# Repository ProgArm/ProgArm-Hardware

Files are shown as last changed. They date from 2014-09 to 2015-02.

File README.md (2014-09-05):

ProgArm-Hardware
================

This repository contains only schematic and PCB files. Schematic PDF and Gerber files are attached to every [release](https://github.com/ProgArm/ProgArm-Hardware/releases).

You can find other files used in ProgArm project [in other repositories](https://github.com/ProgArm). 

Contributing
------------
If you have found a bug, please consider creating an [issue](https://github.com/ProgArm/ProgArm-Hardware/issues). If you have a question, please [ask it on our website](http://progarm.org/Ask).

Please set up these [filters](http://git-scm.com/book/en/Customizing-Git-Git-Attributes) before commiting to this repository:
```
git config --global filter.cleansch.clean "sed 's/^Date.*$/Date \"\"/'"
git config --global filter.cleanlib.clean "sed 's/^\(EESchema-LIBRARY Version [^ \\t]*\).*$/\1/'"
git config --global filter.cleanpcb.clean "sed 's/\(host pcbnew \"\)[^\"]*/\1/'"
git config --global filter.cleanpro.clean "sed 's/^\(update=\).*$/\1/'"
```

License
-------
[According to](https://www.gnu.org/licenses/gpl-faq.html#GPLOtherThanSoftware) Free Software Foundation, GPL license can be applied to anything as long as we can clearly define 'source code'. In this repository all Kicad files are considered as source code files (*.sch *.kicad_pcb *.lib *.mod and several others). You must provide these files (or their modifications) if you are distributing any work based on this project. Please refer to [LICENSE](https://github.com/ProgArm/ProgArm-Hardware/blob/master/LICENSE) file for details.

    ProgArm is free hardware & software: you can redistribute it and/or modify
    it under the terms of the GNU General Public License as published by
    the Free Software Foundation, either version 3 of the License, or
    (at your option) any later version.

    This program is distributed in the hope that it will be useful,
    but WITHOUT ANY WARRANTY; without even the implied warranty of
    MERCHANTABILITY or FITNESS FOR A PARTICULAR PURPOSE.  See the
    GNU General Public License for more details.

    You should have received a copy of the GNU General Public License
    along with this program.  If not, see <http://www.gnu.org/licenses/>.

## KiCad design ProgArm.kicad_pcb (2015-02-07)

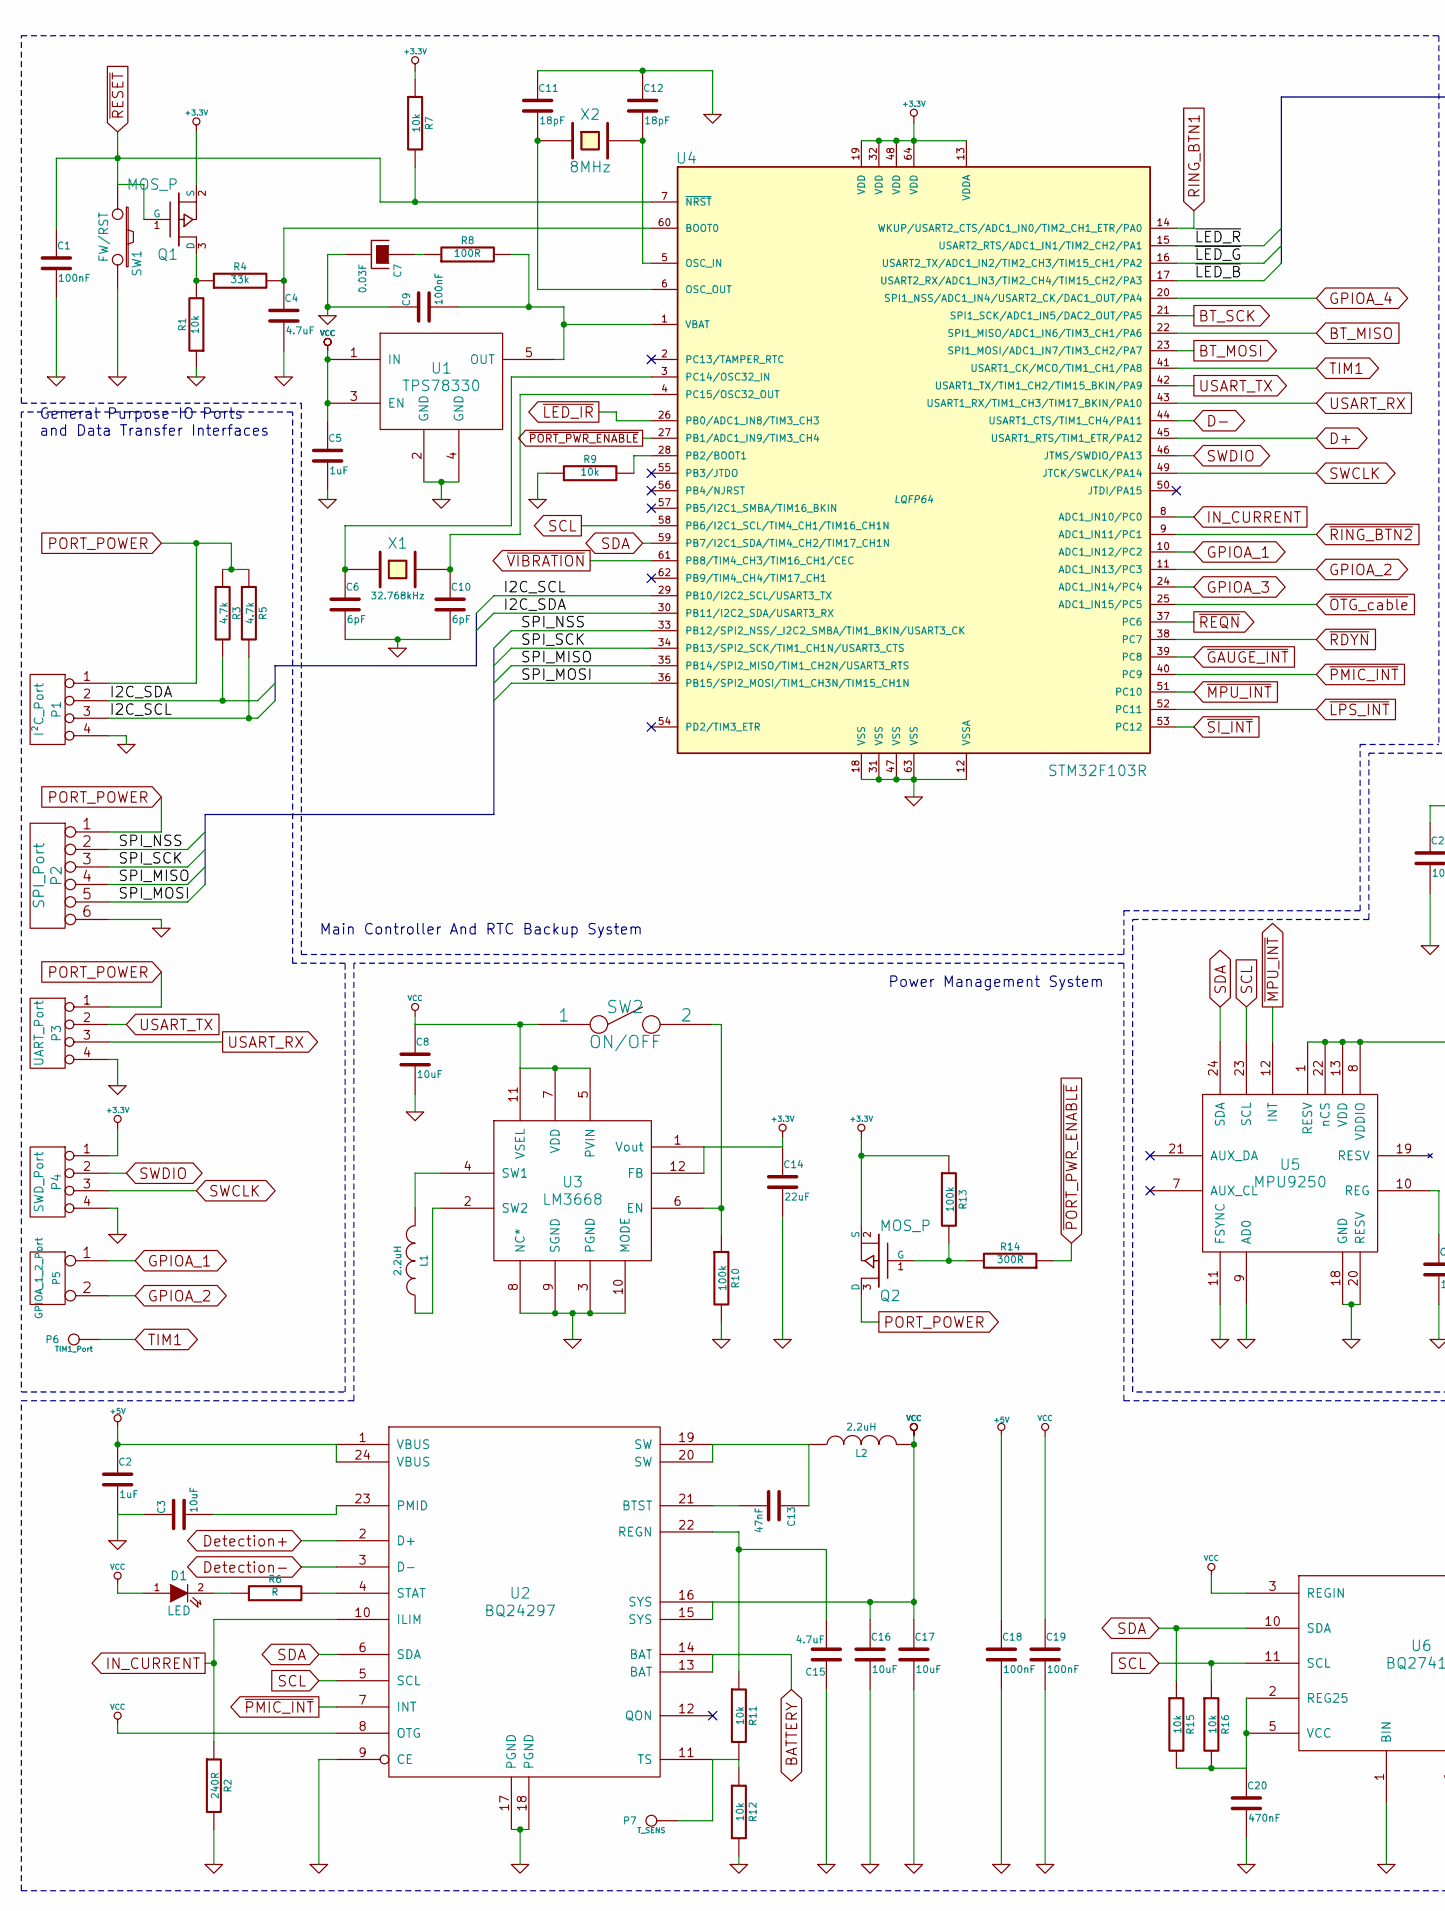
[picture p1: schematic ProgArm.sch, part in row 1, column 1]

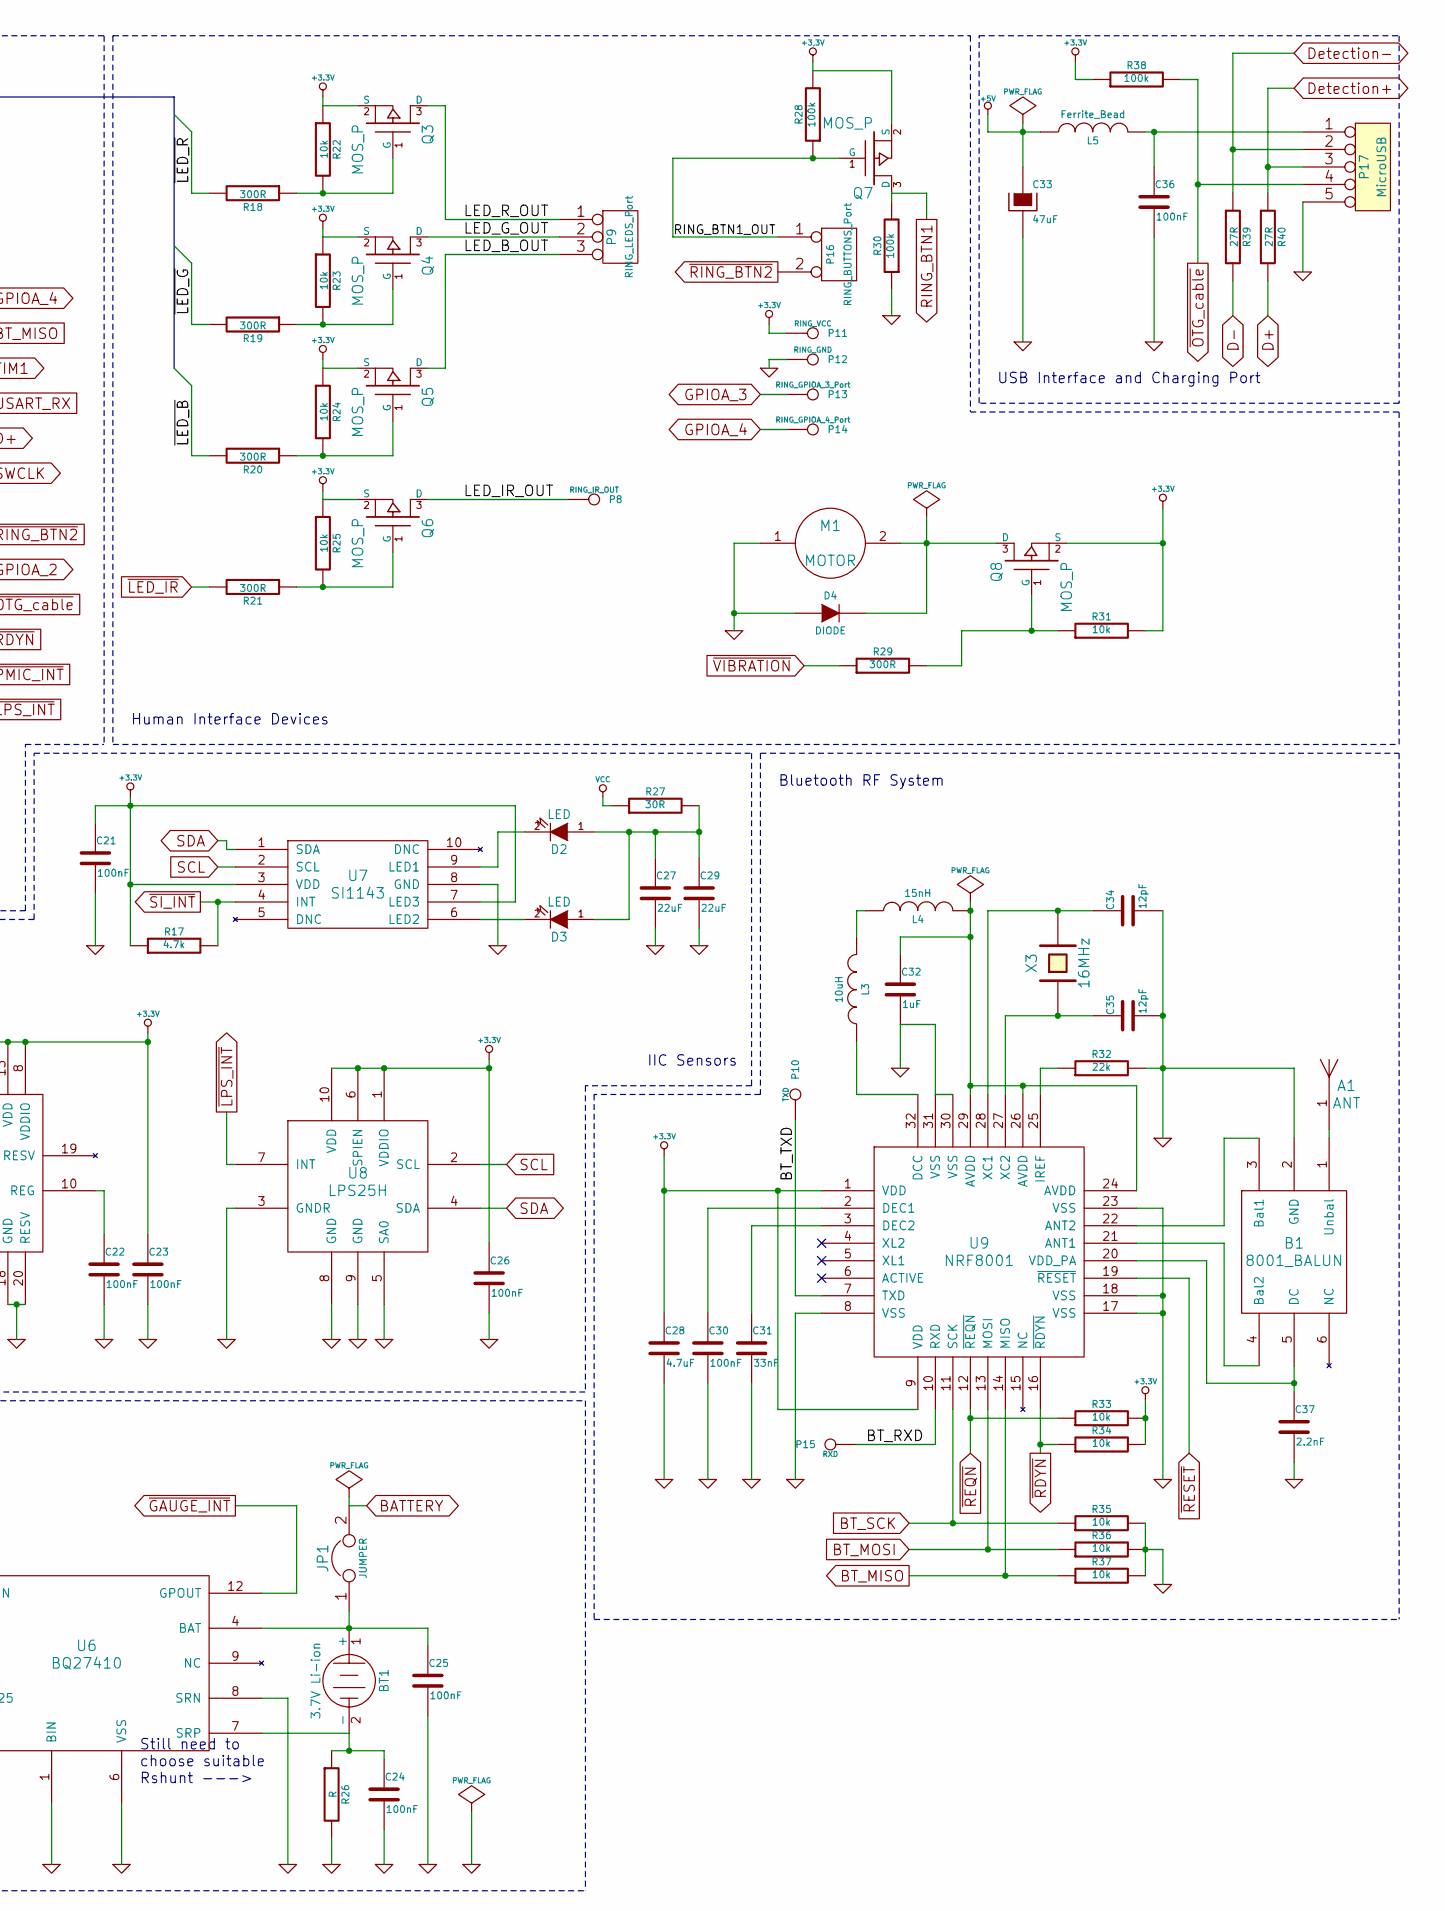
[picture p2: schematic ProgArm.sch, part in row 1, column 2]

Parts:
A1: ANT
B1: 8001_BALUN
BT1: 3.7V Li-ion
C1, C9, C18, C19, C21, C22, C23, C24, C25, C26, C30, C36: 100nF
C2, C5, C32: 1uF
C3, C8, C16, C17: 10uF
C4, C15, C28: 4.7uF
C6, C10: 6pF
C7: 0.03F
C11, C12: 18pF
C13: 47nF
C14, C27, C29: 22uF
C20: 470nF
C31: 33nF
C33: 47uF
C34, C35: 12pF
C37: 2.2nF
D1, D2, D3: LED
D4: DIODE
JP1: JUMPER
L1, L2: 2.2uH
L3: 10uH
L4: 15nH
L5: Ferrite_Bead
M1: MOTOR
P1: I²C_Port
P2: SPI_Port
P3: UART_Port
P4: SWD_Port
P5: GPIOA_1_2_Port
P6: TIM1_Port
P7: T_SENS
P8: RING_IR_OUT
P9: RING_LEDS_Port
P10: TXD
P11: RING_VCC
P12: RING_GND
P13: RING_GPIOA_3_Port
P14: RING_GPIOA_4_Port
P15: RXD
P16: RING_BUTTONS_Port
P17: MicroUSB
Q1, Q2, Q3, Q4, Q5, Q6, Q7, Q8: MOS_P
R1, R7, R9, R11, R12, R15, R16, R22, R23, R24, R25, R31, R33, R34, R35, R36, R37: 10k
R2: 240R
R3, R5, R17: 4.7k
R4: 33k
R6, R26: R
R8: 100R
R10, R13, R28, R30, R38: 100k
R14, R18, R19, R20, R21, R29: 300R
R27: 30R
R32: 22k
R39, R40: 27R
SW1: FW/RST
SW2: ON/OFF
U1: TPS78330
U2: BQ24297
U3: LM3668
U4: STM32F103R; LQFP64
U5: MPU9250
U6: BQ27410
U7: SI1143
U8: LPS25H
U9: NRF8001
X1: 32.768kHz
X2: 8MHz
X3: 16MHz

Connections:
/BT_RXD: P15.1, U9.10 (RXD)
/BT_TXD: P10.1, U9.7 (TXD)
/I2C_SCL: P1.3, R5.2, U4.29 (PB10/I2C2_SCL/USART3_TX)
/I2C_SDA: P1.2, R3.2, U4.30 (PB11/I2C2_SDA/USART3_RX)
/LED_B_OUT: P9.3, Q5.3 (D)
/LED_G_OUT: P9.2 (PM), Q4.3 (D)
/LED_IR_OUT: P8.1, Q6.3 (D)
/LED_R_OUT: P9.1, Q3.3 (D)
/RING_BTN1_OUT: P16.1, Q7.1 (G), R28.1
/SPI_MISO: P2.4, U4.35 (PB14/SPI2_MISO/TIM1_CH2N/USART3_RTS)
/SPI_MOSI: P2.5, U4.36 (PB15/SPI2_MOSI/TIM1_CH3N/TIM15_CH1N)
/SPI_NSS: P2.2, U4.33 (PB12/SPI2_NSS/_I2C2_SMBA/TIM1_BKIN/USAR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)
/SPI_SCK: P2.3, U4.34 (PB13/SPI2_SCK/TIM1_CH1N/USART3_CTS)
/~LED_B: R20.2, U4.17 (USART2_RX/ADC1_IN3/TIM2_CH4/TIM15_CH2/P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)
/~LED_G: R19.2, U4.16 (USART2_TX/ADC1_IN2/TIM2_CH3/TIM15_CH1/P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)
/~LED_R: R18.2, U4.15 (USART2_RTS/ADC1_IN1/TIM2_CH2/PA1)
BATTERY: JP1.2, U2.13 (BAT), U2.14 (BAT)
BT_MISO: R37.1, U4.22 (SPI1_MISO/ADC1_IN6/TIM3_CH1/PA6), U9.14 (MISO)
BT_MOSI: R36.1, U4.23 (SPI1_MOSI/ADC1_IN7/TIM3_CH2/PA7), U9.13 (MOSI)
BT_SCK: R35.1, U4.21 (SPI1_SCK/ADC1_IN5/DAC2_OUT/PA5), U9.11 (SCK)
D+: R40.2, U4.45 (USART1_RTS/TIM1_ETR/PA12)
D-: R39.2, U4.44 (USART1_CTS/TIM1_CH4/PA11)
Detection+: P17.3, R40.1, U2.2 (D+)
Detection-: P17.2, R39.1, U2.3 (D-)
GND: B1.2 (GND), C1.2, C2.2, C3.1, C4.2, C5.2, C6.2, C7.2, C8.2, C9.1, C10.2, C11.1, C12.1, C14.2, C15.1, C16.2, C17.2, C18.2, C19.2, C20.2, C21.2, C22.2, C23.2, C24.2, C25.2, C26.2, C27.2, C28.2, C29.2, C30.2, C31.2, C32.2, C33.2, C34.2, C35.2, C36.2, C37.2, D4.1 (A), M1.0, M1.1, P1.4, P2.6, P3.4, P4.4, P12.1, P17.0, P17.5, R1.1, R2.2, R9.1, R10.2, R12.2, R26.2, R30.1, R32.2, R35.2, R36.2, R37.2, SW1.2, SW2.0, U1.2 (GND), U1.4 (GND), U2.0, U2.9 (CE), U2.17 (PGND), U2.18 (PGND), U3.0, U3.3 (PGND), U3.8 (NC*), U3.9 (SGND), U3.10 (MODE), U4.12 (VSSA), U4.18 (VSS), U4.31 (VSS), U4.47 (VSS), U4.63 (VSS), U5.9 (AD0), U5.11 (FSYNC), U5.18 (GND), U5.20 (RESV), U6.0, U6.1 (BIN), U6.6 (VSS), U6.8 (SRN), U7.8 (GND), U8.3 (GNDR), U8.5 (SA0), U8.8 (GND), U8.9 (GND), U9.0, U9.8 (VSS), U9.17 (VSS), U9.18 (VSS), U9.23 (VSS), U9.30 (VSS), U9.31 (VSS), X3.0
GPIOA_1: P5.1, U4.10 (ADC1_IN12/PC2)
GPIOA_2: P5.2 (PM), U4.11 (ADC1_IN13/PC3)
GPIOA_3: P13.1, U4.24 (ADC1_IN14/PC4)
GPIOA_4: P14.1, U4.20 (SPI1_NSS/ADC1_IN4/USART2_CK/DAC1_OUT/PA4)
IN_CURRENT: R2.1, U2.10 (ILIM), U4.8 (ADC1_IN10/PC0)
unnamed: L3.1, U9.32 (DCC)
unnamed: B1.4 (Bal2), U9.21 (ANT1)
unnamed: B1.5 (DC), C37.1, U9.20 (VDD_PA)
unnamed: B1.3 (Bal1), U9.22 (ANT2)
unnamed: C22.1, U5.10 (REG)
unnamed: C15.2, R11.1, U2.22 (REGN)
unnamed: P7.1, R11.2, R12.1, U2.11 (TS)
unnamed: L3.2, L4.1
unnamed: R32.1, U9.25 (IREF)
unnamed: C31.1, U9.3 (DEC2)
unnamed: C30.1, U9.2 (DEC1)
unnamed: A1.1, B1.1 (Unbal)
unnamed: Q1.3 (D), R1.2, R4.1
unnamed: BT1.2 (-), C24.1, R26.1, U6.7 (SRP)
unnamed: Q2.1 (G), R13.2, R14.2
unnamed: R10.1, SW2.2, U3.6 (EN)
unnamed: L1.1, U3.2 (SW2)
unnamed: L1.2, U3.4 (SW1)
unnamed: R6.2, U2.4 (STAT)
unnamed: D1.2 (K), R6.1
unnamed: C3.2, U2.23 (PMID)
unnamed: C13.1, L2.1, U2.19 (SW), U2.20 (SW)
unnamed: C13.2, U2.21 (BTST)
unnamed: R9.2, U4.28 (PB2/BOOT1)
unnamed: C10.1, U4.4 (PC15/OSC32_OUT), X1.2
unnamed: C9.2, R8.2, U1.5 (OUT), U4.1 (VBAT)
unnamed: C7.1, R8.1
unnamed: C6.1, U4.3 (PC14/OSC32_IN), X1.1
unnamed: Q6.1 (G), R21.1, R25.2
unnamed: C27.1, C29.1, D2.1 (A), D3.1 (A), R27.2
unnamed: D3.2 (K), U7.6 (LED2)
unnamed: D2.2 (K), U7.9 (LED1)
unnamed: C4.1, R4.2, U4.60 (BOOT0)
unnamed: C20.1, R15.2, R16.2, U6.2 (REG25), U6.5 (VCC)
unnamed: D4.2 (K), M1.2, Q8.3 (D)
unnamed: Q3.1 (G), R18.1, R22.2
unnamed: C11.2, U4.6 (OSC_OUT), X2.1
unnamed: C12.2, U4.5 (OSC_IN), X2.2
unnamed: Q5.1 (G), R20.1, R24.2
unnamed: Q4.1 (G), R19.1, R23.2
unnamed: C36.1, L5.2, P17.1
unnamed: BT1.1 (+), C25.1, JP1.1, U6.4 (BAT)
unnamed: C32.1, L4.2, U9.24 (AVDD), U9.26 (AVDD), U9.29 (AVDD)
unnamed: Q8.1 (G), R29.2, R31.1
unnamed: C34.1, U9.28 (XC1), X3.2
unnamed: C35.1, U9.27 (XC2), X3.1
PORT_POWER: P1.1, P2.1, P3.1, Q2.3 (D), R3.1, R5.1
RING_BTN1: Q7.3 (D), R30.2, U4.14 (WKUP/USART2_CTS/ADC1_IN0/TIM2_CH1_ETR/P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)
SCL: R16.1, U2.5 (SCL), U4.58 (PB6/I2C1_SCL/TIM4_CH1/TIM16_CH1N), U5.23 (SCL), U6.11 (SCL), U7.2 (SCL), U8.2 (SCL)
SDA: R15.1, U2.6 (SDA), U4.59 (PB7/I2C1_SDA/TIM4_CH2/TIM17_CH1N), U5.24 (SDA), U6.10 (SDA), U7.1 (SDA), U8.4 (SDA)
SWCLK: P4.3, U4.49 (JTCK/SWCLK/PA14)
SWDIO: P4.2, U4.46 (JTMS/SWDIO/PA13)
TIM1: P6.1, U4.41 (USART1_CK/MCO/TIM1_CH1/PA8)
USART_RX: P3.3, U4.43 (USART1_RX/TIM1_CH3/TIM17_BKIN/PA10)
USART_TX: P3.2, U4.42 (USART1_TX/TIM1_CH2/TIM15_BKIN/PA9)
~GAUGE_INT: U4.39 (PC8), U6.12 (GPOUT)
~LED_IR: R21.2, U4.26 (PB0/ADC1_IN8/TIM3_CH3)
~LPS_INT: U4.52 (PC11), U8.7 (INT)
~MPU_INT: U4.51 (PC10), U5.12 (INT)
~OTG_cable: P17.4, R38.2, U4.25 (ADC1_IN15/PC5)
~PMIC_INT: U2.7 (INT), U4.40 (PC9)
~PORT_PWR_ENABLE: R14.1, U4.27 (PB1/ADC1_IN9/TIM3_CH4)
~RDYN: R34.1, U4.38 (PC7), U9.16 (~RDYN)
~REQN: R33.1, U4.37 (PC6), U9.12 (~REQN)
~RESET: C1.1, Q1.1 (G), R7.2, SW1.1, U4.7 (~NRST), U9.19 (~RESET)
~RING_BTN2: P16.2 (PM), U4.9 (ADC1_IN11/PC1)
~SI_INT: R17.2, U4.53 (PC12), U7.4 (INT)
~VIBRATION: R29.1, U4.61 (PB8/TIM4_CH3/TIM16_CH1/CEC)

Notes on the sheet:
Still need to choose suitable Rshunt --->
Power Management System
IIC Sensors
Bluetooth RF System
Human Interface Devices
USB Interface and Charging Port
Main Controller And RTC Backup System
General Purpose IO Ports and Data Transfer Interfaces

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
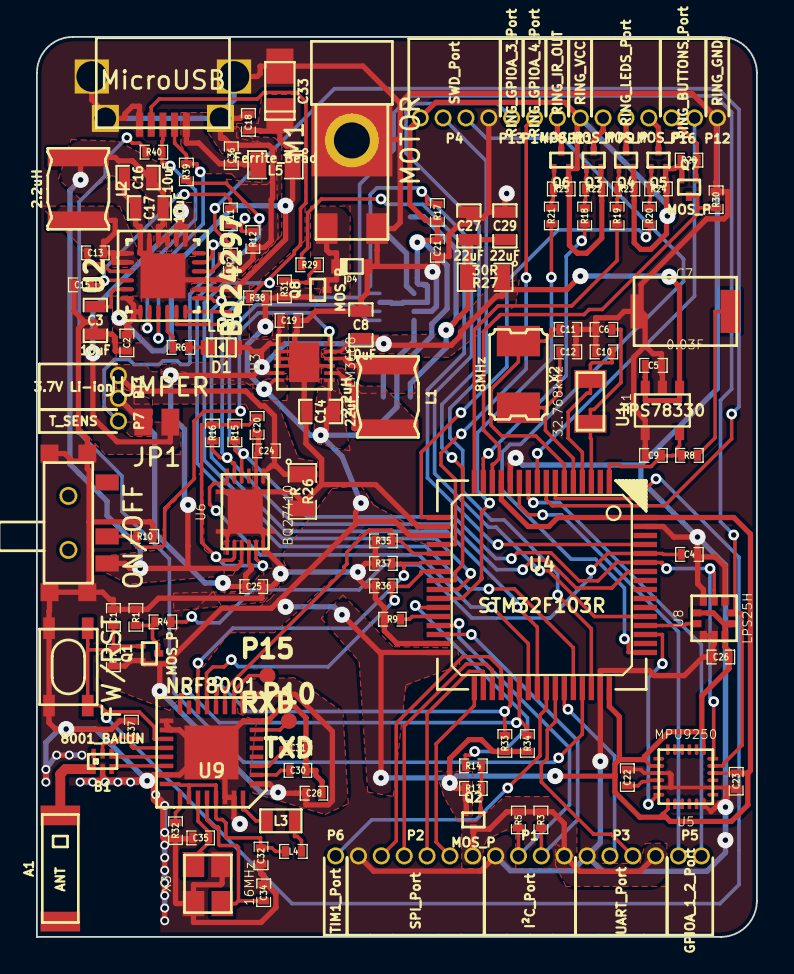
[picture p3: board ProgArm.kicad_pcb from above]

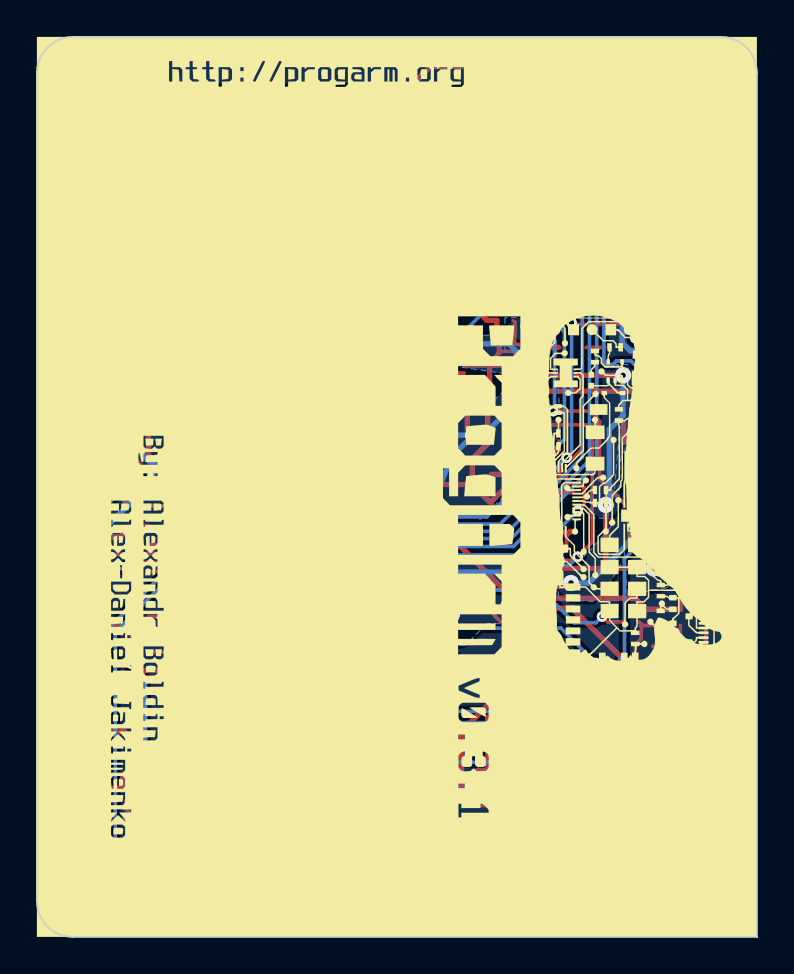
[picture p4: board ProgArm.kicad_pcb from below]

Board: 2 copper layers, 40.0 x 50.0 mm, 131 parts (3 on the bottom side), 101 nets.

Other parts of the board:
VAL: REF; progarm_logo

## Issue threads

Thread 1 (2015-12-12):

No 1.5kOhm pull-up on D+ line

AlexDaniel, 2015-12-12:
One careful person asked this question by email:

> I was wondering, where is 1.5 kOhm pull-up on D+ line?

Indeed! It seems like it is an error on schematic. USB communication was not tested yet, so no wonder that this problem went unnoticed.

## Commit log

2014-06-03 Initial commit. ProgArm 0.1
    [arm.dsn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]
2014-06-03 Fixed external SPI port connection
2014-06-04 True PWM pins for ring port
    [arm.sch]
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2014-06-06 Git filters in action
    [arm.sch]
2014-06-07 Fixed git filter
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2014-06-07 6-pin ring port, RING_BTN2
    [arm.sch]
2014-06-07 Both PIO0 and PIO11 are connected to BT_KEY now. This is required for HM-10 and HC-05 compatibility.
    [arm.sch]
2014-06-07 Implemented an LTC3566-2 power management IC as primary power source / charge controller instead of previous problematic build.
    [arm.sch]
2014-06-08 added piezo buzzer instead of old one
    [arm.sch]
2014-06-09 New super convenient push-button flashing system!
    [arm.sch]
2014-06-10 removed unneeded resistor in flash-enable circuit
    [arm.sch]
2014-06-11 Removed unnecessary RESET global label
    [arm.sch]
2014-06-14 SPI_NSS, extra components for soldering
    [arm.sch]
2014-06-16 i2c pullups set to sys_power, modified firmware switch
    [arm.sch]
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2014-06-18 Added new component to the STM32 library: STM32F103R8; replaced current MCU with it due to more pins required
    [arm.sch]
2014-06-18 Added JTAG, Reassigned pins used by JTAG to PC0-PC15, Connected #PWM_MODE flag, minor fixes and improvements
    [arm.sch]
2014-06-18 Minor visual improvement with BOOT1 pin
    [arm.sch]
2014-06-18 BT_KEY is now near to other BT pins
    [arm.sch]
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2014-06-18 Reassigned SD_CD to pin 24, so that SD card pins would be in order
    [arm.sch]
2014-06-18 new look for inverted global labels (using "~" instead of "#")
    [arm.sch]
2014-06-18 new names for global labels because Alex-Daniel wanted so -_-
    [arm.sch]
2014-06-18 Rearranged MOSFET pullup resistors, ~CHARGE and ALERT moved to PC2 and PC3
    [arm.sch]
2014-06-18 schematic layout changes because Plex-Daniel wanted so...
    [arm.sch]
2014-06-19 Fixed LTC3566 (EXPAD pin number set to 0, made component wider, so that all text would fit)
    [arm.sch]
2014-06-19 Fixed LED bus names
    [arm.sch]
2014-06-19 Not connected pins, minor fixes
    [arm.sch]
2014-06-19 Automatic annotation, generated netlist
    [arm.sch]
2014-06-19 Slowly setting correct footprints
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2014-06-19 More visual improvements, BT bus separated from RING bus, Authors' names
    [arm.sch]
2014-06-19 Renaming all files. arm->ProgArm
    [ProgArm.kicad_pcb, ProgArm.sch]
2014-06-19 Removing outdated specctra and gerber files
    [arm.dsn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]
2014-06-19 Forgot to add PC13 to unused pins. This is now fixed
    [ProgArm.sch]
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2014-06-19 Added separate switchable power line for external ports (~PRT_PWR_ENABLE and PRT_POWER)
    [ProgArm.sch]
2014-06-20 Reorganized the whole schematic! Readability counts.
    [ProgArm.sch]
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2014-06-20 MPU and HMC are using the same 15-10 interrupt now
    [ProgArm.sch]
2014-06-20 Deleted unnecessary library files, replaced our own components with Walter Lain's libraries, moved all library files to 'library' and 'modules' folder, strict convention in component naming (all file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
    [ProgArm.sch]
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2014-06-21 Fixed file permissions, separated buzzer nad stm32f103r components from ProgArm-cache, other minor fixes
    [ProgArm.sch]
2014-06-21 Fixed library order, motor and buzzer are moved into misc.lib, fixed mosfet components, ~OVERLINE for ring led and ring_button2, other minor improvements
    [ProgArm.sch]
2014-06-21 Inverted ALERT, MPU_INT and HMC_INT
    [ProgArm.sch]
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2014-06-21 removed a resistor on MPU_INT
    [ProgArm.sch]
2014-06-21 Setting up footprints. Halfway there (1pin indicates unset footprint)
    [ProgArm.sch]
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2014-06-21 Fixed pin numbering in side switch footprint
2014-06-21 Still setting up footprints! Fixed Ring_Port name (was CONN_6), changed INDUCTOR to Ferrite_Bead
    [ProgArm.sch]
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2014-06-22 Changed directory structure, added 3d files, corrected some footprints in netlist
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2014-06-22 Netlist read! Everything is ready for PCB development. Added kicad_pcb-bak to .gitignore
    [ProgArm.kicad_pcb]
2014-06-22 Revision version specified (0.2), Copyright notice in kicad_pcb file
    [ProgArm.kicad_pcb, ProgArm.sch]
2014-06-22 First try of PCB components positioning
    [ProgArm.kicad_pcb]
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2014-06-22 trying to make PCB
    [ProgArm.dsn, ProgArm.kicad_pcb]
2014-06-22 GND on usb body, no exposed pad for MPU
    [ProgArm.kicad_pcb]
2014-06-22 LTC3566 exposed pad connected to GND
    [ProgArm.kicad_pcb]
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2014-06-23 New board layout attempt
    [ProgArm.dsn, ProgArm.kicad_pcb]
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2014-06-26 Another attempt. Components placed
    [ProgArm.dsn, ProgArm.kicad_pcb]
2014-06-26 Optimized tracks (120 vias, 3,092...)
    [ProgArm.dsn]
2014-06-27 Rearranged PCB Power layout
    [ProgArm.dsn, ProgArm.kicad_pcb]
2014-06-27 Fixed spacing between pins
    [ProgArm.kicad_pcb]
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2014-06-28 LQFP64 pin width changed to 0.3mm, added HMC ground track (otherwise it wont route), updated .dsn file
    [ProgArm.dsn, ProgArm.kicad_pcb]
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2014-06-30 Hacked ProgArm.kicad_pcb file to add another net for LTC2942-1 exposed pad
    [ProgArm.kicad_pcb]
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2014-06-30 Slightly moved tracks and vias to achieve amazing fill zones
    [ProgArm.dsn, ProgArm.kicad_pcb]
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2014-06-30 An attempt to separate exposed pad from pins
    [ProgArm.kicad_pcb]
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2014-06-30 Added cutout area for hmc and mpu (GND was filling inside like an exposed pad)
    [ProgArm.kicad_pcb]
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2014-06-30 All ground pins are now rectangular (keep in mind that .dsn was not changed)
    [ProgArm.kicad_pcb]
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2014-07-01 Slightly modified logo (version number, text moved a little bit so that through-holes do not cover letters)
    [ProgArm.kicad_pcb]
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2014-07-01 Fixed email address
    [ProgArm.kicad_pcb, ProgArm.sch]
2014-07-02 Gerber files are now removed from git repo. Please see Releases (tags) on github to get gerbers and schematic(pdf)
    [ProgArm-B_Cu.gbl, ProgArm-B_Mask.gbs, ProgArm-B_SilkS.gbo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]
2014-07-24 Major bug fix! Added delay system at BOOT0 to prevent STM32 forcing itself into flasing mode after each reset.
    [ProgArm.sch]
2014-08-18 Adjusted some pullup resistors values for better PWM
    [ProgArm.sch]
2014-08-18 Added missing component numbers
    [ProgArm.sch]
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2014-11-09 Removed compass component (we will use something that is integrated with accelgyro)
    [ProgArm.sch]
2014-11-10 Changed SYS_POWER to 3.3v in I2C pullups (because battery chips are always on)
    [ProgArm.sch]
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2014-11-15 Replaced BMP180 with LPS25H, changed HMC_INT to LPS_INT
    [ProgArm.sch]
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2014-11-17 Replaced LTC2942 with bq27410. COrrections still needed,
    [ProgArm.sch]
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2014-11-24 -Replaced LTC3566 with bq24297 -Removed SYS_Power plane, now it's powered from 3.3v -Added dedicated buck-boost converter (lm3668) -Added OTG cable detection and input current sense -Removed 100uF ta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
    [ProgArm.sch]
2014-11-25 Replaced HC05 with custom BT module (nRF51822)
    [ProgArm.sch]
2014-11-25 Fixed Rx Tx pins on BT Chip
    [ProgArm.sch]
2014-11-25 Fixed not connected SD_CD pin
    [ProgArm.sch]
2014-11-25 one of the BT_AVDD power flags should have been set as output
    [ProgArm.sch]
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2014-12-02 Replaced nRF51 series chip with nRF8001; removed SD_CARD
    [ProgArm.sch]
2014-12-03 Added IR LED and Sensor connections for ring port
    [ProgArm.sch]
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2014-12-03 Removed useless elements (buzzer signals, solder ports, NC pins etc.)
    [ProgArm.sch]
2014-12-04 Removed unused third LED in the pulse sensor schematic
    [ProgArm.sch]
2014-12-05 Issue with bluetooth pull-downs
    [ProgArm.sch]
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2014-12-08 Fixed issues from the list, added block-style grouping
    [ProgArm.sch]
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2014-12-08 Pulse meter LEDs are now powered from VCC
    [ProgArm.sch]
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2014-12-08 Components numeration, description fixes
    [ProgArm.sch]
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2014-12-09 Fixed bq27410 footprint
2014-12-09 Fixed qfn-10 footprint
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2014-12-10 Fixed antenna pin number, changed footprints for BT TXD and RXD
    [ProgArm.kicad_pcb, ProgArm.sch]
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2014-12-11 Central pads connected to GND (according to datasheets), no holes on central pads, smaller size for TXD and RXD pads
    [ProgArm.kicad_pcb]
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2014-12-11 Changing trace widths (and rounding it to mm)
    [ProgArm.kicad_pcb]
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2014-12-13 Fixed inductor and switch footprints
2014-12-13 Revert "Fixed inductor and switch footprints"
    (Netnames inside the library files)
    This reverts commit 9a7367a608264bf1beca435706c64097ef592859.
2014-12-13 Fixed inductor and switch footprints (seriously this time)
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2014-12-13 Small fixed, tracks imported
    [ProgArm.kicad_pcb]
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2014-12-18 Small fixes, thick power traces
    [ProgArm.dsn, ProgArm.kicad_pcb]
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2014-12-18 Board Optimized: Via count: 100 Trace Lenght: 2,515,295,8805
    [ProgArm.dsn, ProgArm.kicad_pcb]
2014-12-20 Small fixes for proper power tracks
    [ProgArm.dsn, ProgArm.kicad_pcb]
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2014-12-21 Beautified pours, some fixes
    [ProgArm.kicad_pcb]
2014-12-23 More fixes for pours
    [ProgArm.kicad_pcb]
2014-12-24 Made some changes to the antenna in accordance to app note
    [ProgArm.kicad_pcb]
2014-12-24 Better NRF central pad pour, wider GND pour near to it
    [ProgArm.kicad_pcb]
2014-12-24 Fixed GND VIA at nRF8001 chip
    [ProgArm.kicad_pcb]
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2014-12-25 Some fixes for pours
    [ProgArm.kicad_pcb]
2014-12-26 Small fixes, DRC pass (almost)
    [ProgArm.kicad_pcb]
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2014-12-26 Regular through-holes instead of NPTH (only one file is allowed in itead)
    [ProgArm.kicad_pcb]
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2014-12-29 Fixed one huge Fuckup
    [.kicad_pcb.kicad_pcb, ProgArm.kicad_pcb]
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2015-01-04 Corrected bottom silkscreen, no through-holes on our names
    [ProgArm.kicad_pcb]
2015-02-07 Fixed OTG activation pin, should now work
    [ProgArm.sch]
2015-02-07 Added missing resistor values, changed Rilim to limit current at around 580mA
    [ProgArm.sch]
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

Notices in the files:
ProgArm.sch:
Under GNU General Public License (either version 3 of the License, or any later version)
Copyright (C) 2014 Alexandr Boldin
